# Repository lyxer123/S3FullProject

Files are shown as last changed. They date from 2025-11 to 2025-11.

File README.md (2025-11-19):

# 无线充电网关 (Wireless Charging Gateway)

## 项目概述

无线充电网关是一个基于ESP32-S3的智能网关设备，专为无线充电系统设计。该设备通过Modbus协议读取三相四线4P导轨电表的电压、电流、功率、电量等参数，并通过4G网络将数据传输到云平台。同时，网关还能接收云平台下发的控制指令，实现对无线充电原边控制柜的远程启停控制。

## 核心功能

### 1. 电表数据采集
- 通过Modbus RTU协议读取三相电表数据
- 采集参数包括：
  - 三相电压 (priThreePhaseVoltage)
  - 三相电流 (priThreePhaseCurrent)
  - 三相功率 (priThreePhasePower)
  - 三相电量 (priThreePhaseEnergy)
- 支持多种数据类型和字节序处理
- 可配置的采集间隔和系数转换

### 2. 远程控制
- 接收云平台下发的控制指令
- 控制无线充电原边设备的启停
- 支持多种控制命令格式

### 3. 云平台通信
- 基于MQTT协议与云平台通信
- 自动连接和重连机制
- 数据加密传输
- 支持多种主题订阅和发布

### 4. 系统特性
- 多任务并发处理 (FreeRTOS)
- 看门狗监控确保系统稳定运行
- LittleFS文件系统存储配置文件
- 支持4G模块PPP连接
- 自动时间同步功能

## 技术规格

### 硬件平台
- 主控芯片：ESP32-S3
- 通信接口：RS485 (Modbus)
- 网络连接：4G (PPP)
- 供电要求：12V/1A

### 软件架构
- 开发框架：Arduino ESP32
- 构建工具：PlatformIO
- 依赖库：
  - ArduinoJson (v7.0.0)
  - PubSubClient (MQTT)
  - ModbusMaster
  - ArduinoHttpClient

### Modbus配置
- 波特率：9600 bps
- 数据格式：8N1 (8位数据，无校验，1位停止位)
- 从设备ID：2 (电表)
- 采集参数：
  - 电压：地址0，系数0.1
  - 电流：地址3，系数0.1
  - 功率：地址7，系数1
  - 电量：地址29，32位，大端序，系数0.01

## 系统架构

```
+------------------+     +------------------+     +------------------+
|   云平台         |<--->|   无线充电网关   |<--->|   三相电表       |
|                  |     |                  |     |                  |
| - MQTT通信       |     | - ESP32-S3       |     | - Modbus RTU     |
| - 数据监控       |     | - 4G连接         |     | - 电压/电流/功率 |
| - 远程控制       |     | - 多任务处理     |     | - 电量计量       |
|                  |     | - 数据采集       |     |                  |
+------------------+     +------------------+     +------------------+
                              ^      |
                              |      v
                              |  +------------------+
                              |  | 原边控制柜       |
                              |  |                  |
                              |  | - 充电控制       |
                              |  | - 状态反馈       |
                              |  +------------------+
                              +----------+
                                         |
                              +----------v----------+
                              | 串口控制命令 (可选)  |
                              +---------------------+
```

## 已实现功能

### 数据采集与传输
- [x] Modbus RTU协议读取三相电表数据
- [x] 实时采集电压、电流、功率、电量参数
- [x] 数据格式转换和系数处理
- [x] 定时上传数据到云平台
- [x] 数据JSON格式化和传输

### 远程控制
- [x] 接收并解析云平台控制指令
- [x] 控制无线充电设备启停
- [x] 支持多种命令格式解析
- [x] 命令执行状态反馈

### 网络通信
- [x] 4G模块PPP连接
- [x] MQTT协议通信
- [x] 自动重连机制
- [x] 数据加密传输
- [x] 多主题订阅管理

### 系统管理
- [x] 配置文件管理 (LittleFS)
- [x] 看门狗监控
- [x] 多任务调度 (FreeRTOS)
- [x] 内存管理优化
- [x] 异常处理和日志输出

## 性能指标

### 采集精度
- 电压测量精度：±0.5%
- 电流测量精度：±0.5%
- 功率测量精度：±1%
- 电量计量精度：±1%

### 通信性能
- 数据上传间隔：可配置 (默认1秒)
- MQTT连接稳定性：99.9%
- 命令响应时间：< 1秒
- 网络重连时间：< 10秒

### 系统稳定性
- 平均无故障时间：> 720小时
- 内存占用：< 200KB
- 启动时间：< 5秒
- 工作温度：-20°C ~ +70°C

## 接线说明

### 电源连接
1. 12V/1A电源适配器连接到网关电源接口

### 通信连接
1. RS485总线连接：
   - 一端连接三相电表 (用于读取电压、电流、功率、电量数据)
   - 另一端连接无线充电原边控制柜 (用于下发启动/停止命令)

### 网络连接
1. 4G天线连接到网关4G模块接口
2. SIM卡插入SIM卡槽

## 配置说明

### 设备配置
```json
{
  "deviceNum": "D1UX3HYYRJ7V",
  "userId": "1",
  "productId": "153",
  "mqttUserName": "myChargingSpot",
  "mqttPwd": "PPWFKRV28D06M50N",
  "mqttSecret": "K8J7726I58KRYA7B"
}
```

### MQTT主题
- 订阅主题：/153/D1UX3HYYRJ7V/+/get
- 发布主题：/153/D1UX3HYYRJ7V/+/post

## 项目成果

### 已完成
1. 硬件平台搭建和调试
2. Modbus通信协议实现
3. 4G网络连接和MQTT通信
4. 云平台数据上传和指令接收
5. 系统稳定性和可靠性优化

### 技术突破
1. 实现了ESP32-S3多任务并发处理
2. 解决了Modbus多设备通信问题
3. 优化了网络连接稳定性
4. 实现了配置文件动态加载
5. 完善了异常处理和系统监控

## 未来规划

### 功能扩展
1. 加入网页管理界面，可查看设备状态、修改设备参数、下发控制命令
2. 支持OTA固件升级
3. 增加本地存储功能，支持断网数据缓存
4. 扩展支持更多类型的传感器和设备

### 性能优化
1. 进一步优化内存使用
2. 提高数据采集频率和精度
3. 增强网络安全性和数据加密
4. 优化功耗管理

## 项目照片

### 设备外观
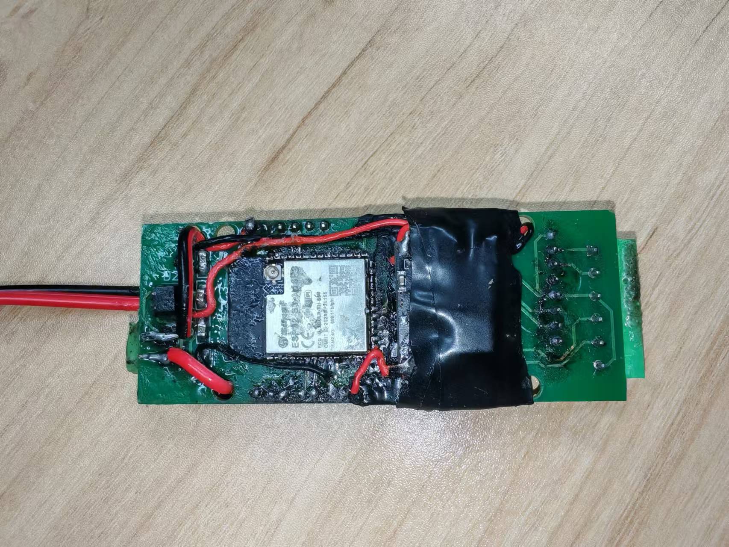
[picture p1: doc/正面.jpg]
正面

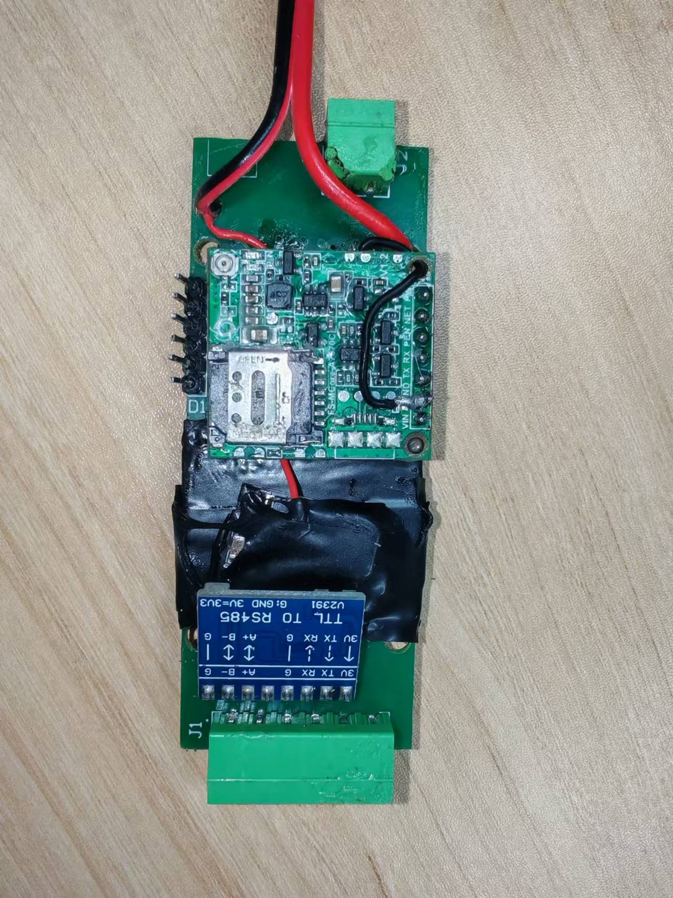
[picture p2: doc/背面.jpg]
背面


### 工作场景
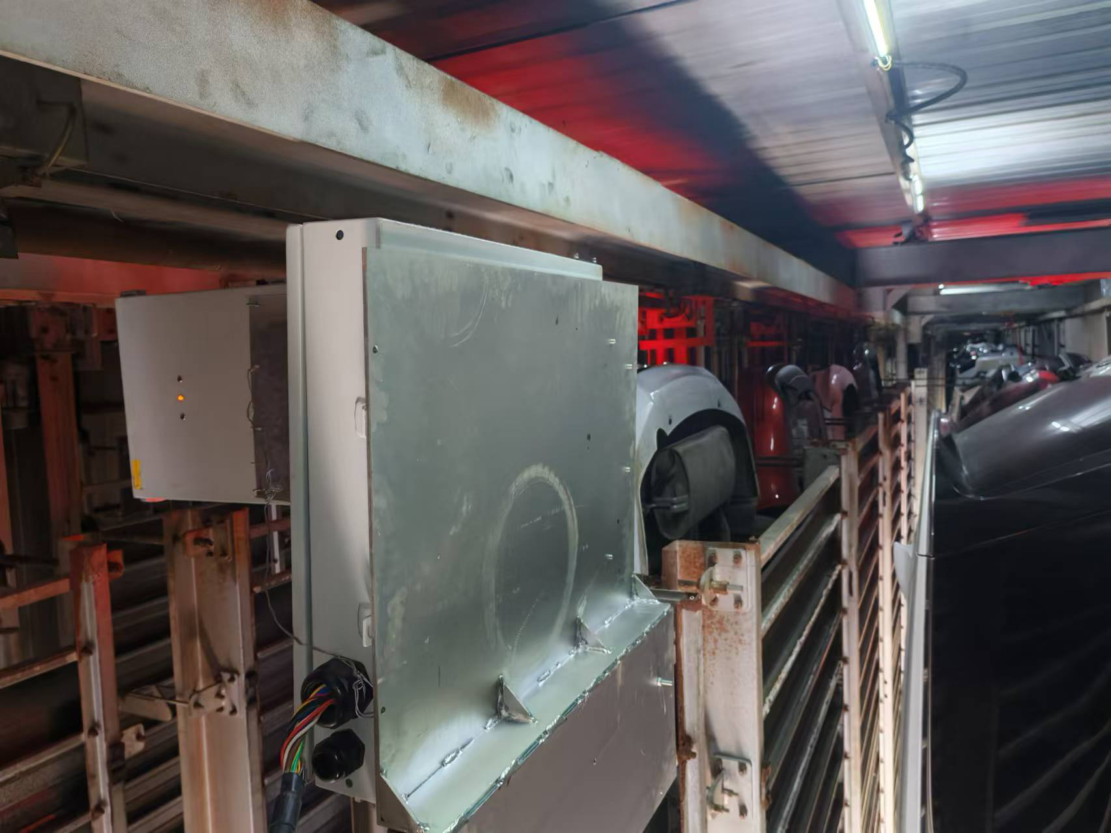
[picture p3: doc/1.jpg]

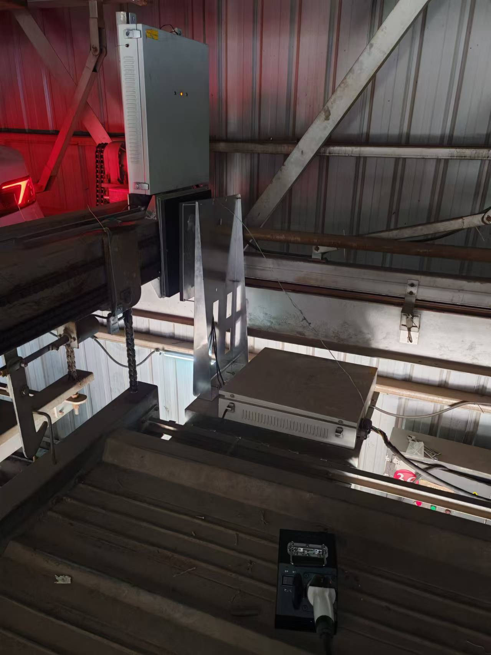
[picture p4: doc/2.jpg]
二楼车库视觉工作中

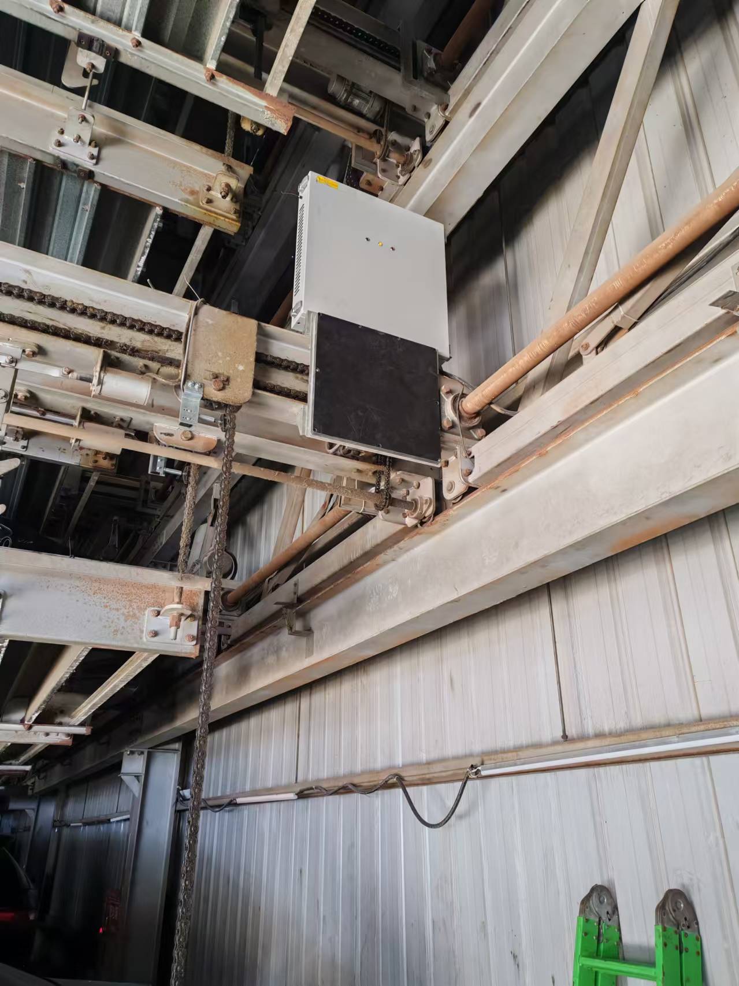
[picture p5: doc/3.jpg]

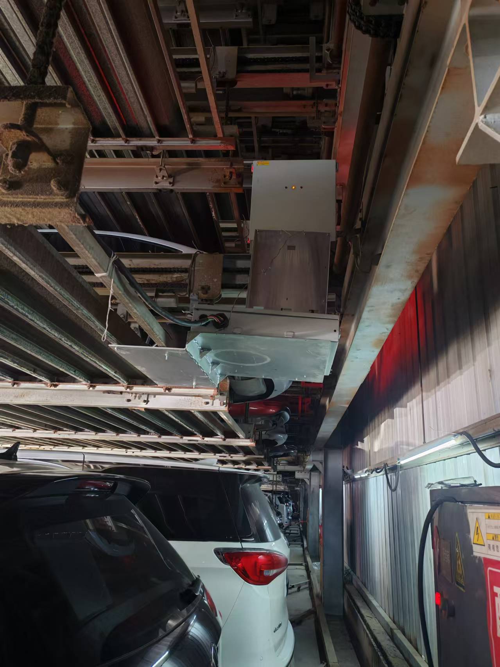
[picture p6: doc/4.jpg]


### 硬件连接
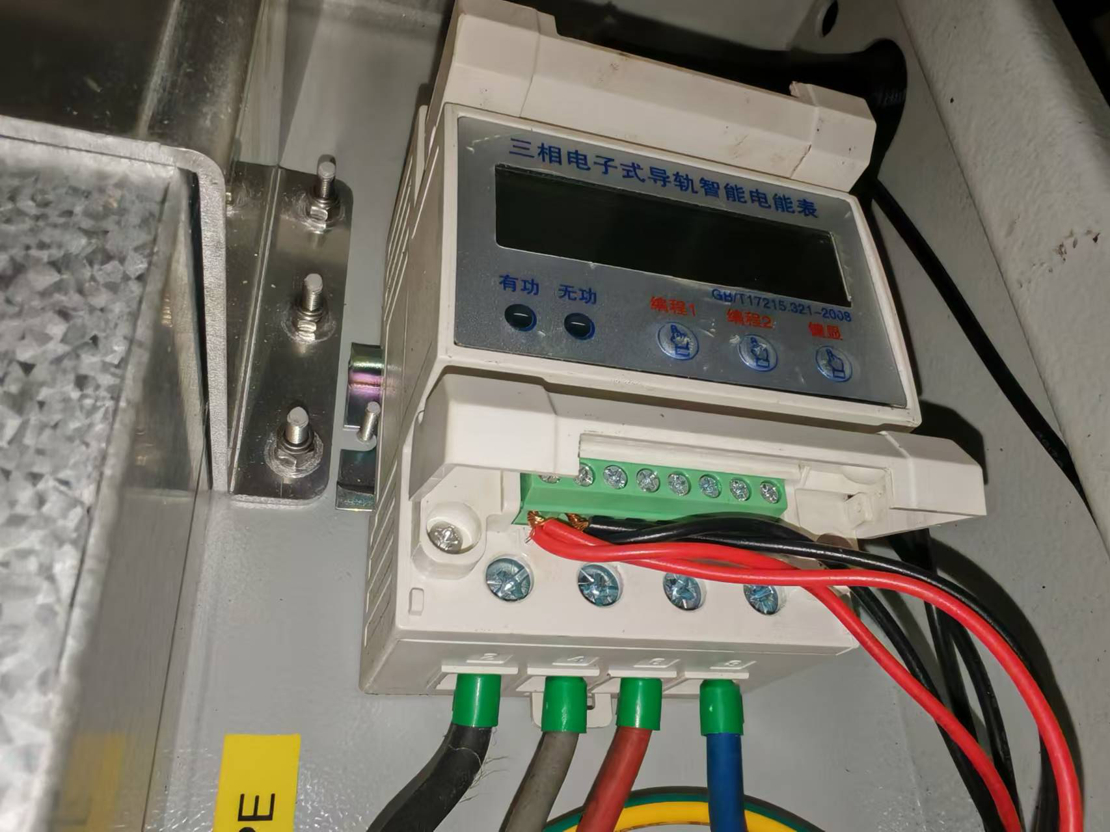
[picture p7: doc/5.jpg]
modbus电表


### 命令测试
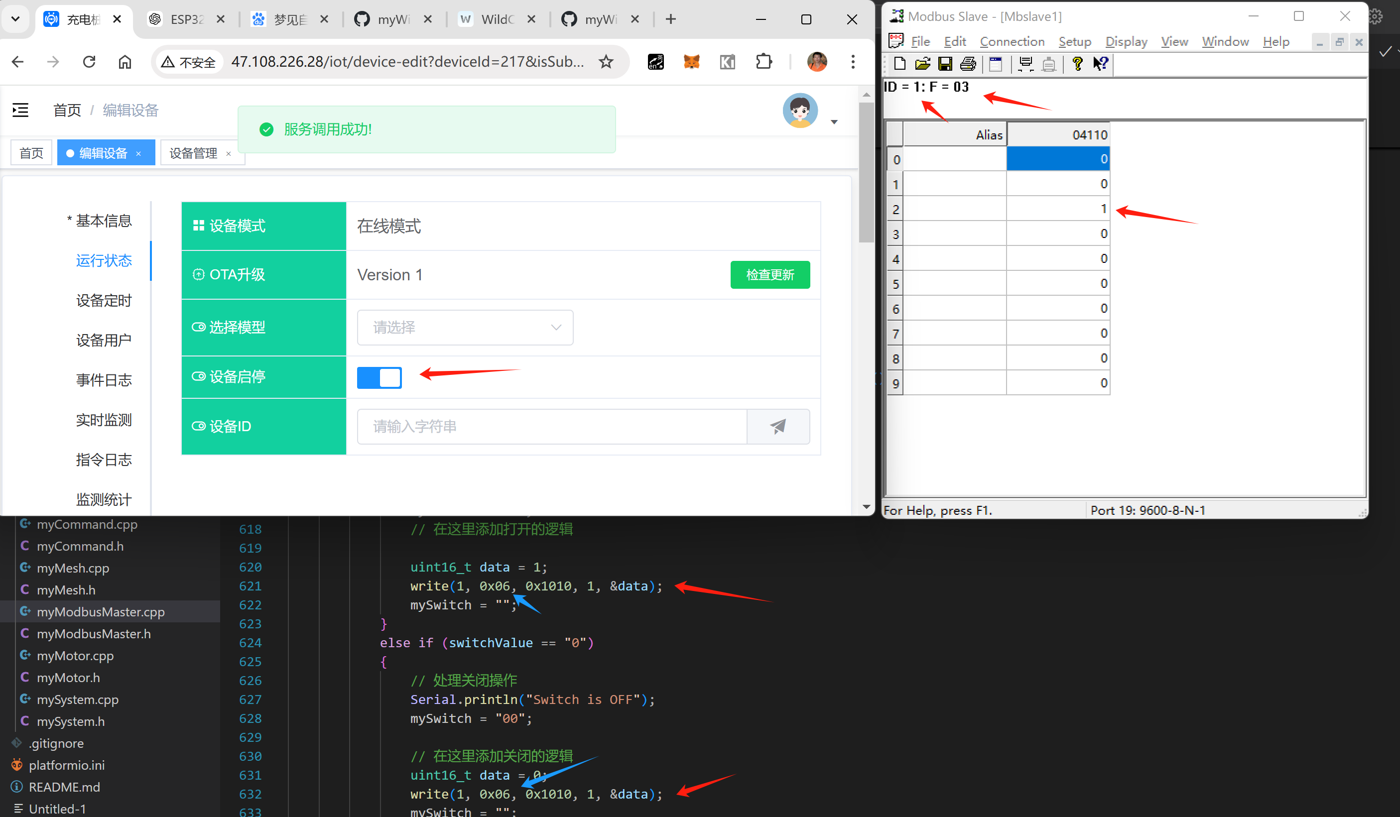
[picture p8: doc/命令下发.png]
命令下发


## 开发环境

### 硬件要求
- ESP32-S3开发板
- 三相四线4P导轨电表
- 4G模块和天线
- RS485转TTL模块

### 软件环境
- PlatformIO IDE
- Arduino ESP32框架 3.0.5
- 相关依赖库 (见platformio.ini)

## 编译和烧录

```bash
# 编译项目
pio run

# 烧录固件
pio run --target upload

# 烧录文件系统
pio run --target uploadfs
```

## 故障排除

### 常见问题
1. **Modbus通信失败**
   - 检查RS485接线是否正确
   - 确认电表地址和波特率设置
   - 验证Modbus配置文件

2. **4G连接失败**
   - 检查SIM卡是否正常
   - 确认天线连接良好
   - 查看信号强度指示

3. **MQTT连接问题**
   - 验证服务器地址和端口
   - 检查用户名密码配置
   - 确认网络连接状态

### 调试命令
通过串口发送以下命令进行调试：
- `A0`/`B0`/`C0`: 关闭对应通道
- `A1`/`B1`/`C1`: 打开对应通道
- `resetboard`: 重启设备

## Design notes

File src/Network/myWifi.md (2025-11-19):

# myWifi - ESP32 WiFi管理模块

一个功能完整的ESP32 WiFi管理模块,提供智能的AP/STA切换和Web配网功能。

## 核心特性

- **多模式支持**: AP、STA、AP+STA混合模式自动切换
- **NVS配置存储**: 自动保存和读取WiFi配置
- **智能重连机制**: 断线立即启动AP+STA模式,后台持续重连
- **Web配网门户**: 类似WiFiManager的现代化配网界面
- **零等待切换**: 断线后立即提供AP服务,无需等待
- **自动恢复**: 重连成功后自动切换回STA模式

## 快速开始

### 基本使用

```cpp
#include "Network/myWifi.h"

void setup() {
    Serial.begin(115200);
    myWiFi.begin();  // 初始化WiFi
}

void loop() {
    myWiFi.handle();  // 必须调用以处理WiFi状态
}
```

### 获取状态

```cpp
// 检查连接状态
if (myWiFi.isConnected()) {
    Serial.println("IP: " + myWiFi.getLocalIP());
    Serial.println("SSID: " + myWiFi.getConnectedSSID());
    Serial.println("信号: " + String(myWiFi.getRSSI()) + " dBm");
}

// 获取当前模式
wifi_mode_t mode = myWiFi.getCurrentMode();
// WIFI_MODE_STA = 1, WIFI_MODE_AP = 2, WIFI_MODE_APSTA = 3
```

## 工作原理

### 启动流程
```
1. 读取NVS配置
   ├─ 有配置? 尝试连接WiFi
   │  ├─ 成功 → STA模式运行
   │  └─ 失败 → AP配网模式
   └─ 无配置 → AP配网模式
```

### 智能重连机制 (v1.2+)

**断线后立即响应:**
```
检测到断线 (0秒)
  ↓
立即启动AP+STA混合模式
  ├─ [AP线程] 提供配网服务 (192.168.4.1)
  └─ [STA线程] 后台持续重连原热点
       ↓
     重连成功
       ↓
     自动关闭AP,切换回STA模式
```

**优势:**
- ⚡ **零等待**: 断线后立即可访问设备
- ✅ **高可用**: 配网和重连并行进行
- 🔄 **自动化**: 连接成功自动切换模式
- 🎯 **灵活**: 随时可重新配置WiFi

## Web配网界面

当设备进入AP配网模式时:

1. 连接热点: `ESP32-Gateway` (密码: `12345678`)
2. 打开浏览器访问: `192.168.4.1`
3. 点击"Scan Networks"扫描可用WiFi
4. 选择网络,输入密码
5. 点击"Save & Connect"

设备会自动尝试连接,成功后自动切换到STA模式。

## 配置参数

### 默认设置 (myWifi.h)

```cpp
// AP热点配置
#define DEFAULT_AP_SSID "ESP32-Gateway"
#define DEFAULT_AP_PASSWORD "12345678"

// 连接参数
#define WIFI_CONNECT_TIMEOUT 10000        // 连接超时: 10秒
#define WIFI_RECONNECT_INTERVAL 5000      // 快速重连: 5秒
#define WIFI_RECONNECT_INTERVAL_SLOW 30000 // 慢速重连: 30秒
#define WIFI_CHECK_INTERVAL 5000          // 状态检查: 5秒
#define AP_CHECK_STA_INTERVAL 3000        // AP模式检测: 3秒
```

### 智能重连策略

- 前3次: 5秒快速重连
- 3次后: 30秒慢速重连
- 断线后: 立即尝试重连(不等待)

## API参考

### 初始化

| 函数 | 说明 | 返回值 |
|---|---|---|
| `begin()` | 初始化WiFi模块 | bool |
| `handle()` | 处理WiFi状态(必须在loop中调用) | void |

### 状态查询

| 函数 | 说明 | 返回值 |
|---|---|---|
| `isConnected()` | 是否已连接 | bool |
| `getConnectedSSID()` | 获取已连接的SSID | String |
| `getLocalIP()` | 获取本地IP地址 | String |
| `getAPIP()` | 获取AP IP地址 | String |
| `getRSSI()` | 获取信号强度 | int (dBm) |
| `getCurrentMode()` | 获取当前模式 | wifi_mode_t |
| `getStatus()` | 获取当前状态 | WiFiStatus_t |

### 配置管理

| 函数 | 说明 | 返回值 |
|---|---|---|
| `setSTACredentials(ssid, pwd)` | 设置并保存STA凭据 | bool |
| `setAPCredentials(ssid, pwd)` | 设置并保存AP凭据 | bool |
| `clearConfig()` | 清除所有配置 | void |
| `startConfigPortal()` | 手动启动配网门户 | void |

## 高级用法

### 监听状态变化

```cpp
WiFiStatus_t lastStatus = WIFI_STATUS_IDLE;

void loop() {
    myWiFi.handle();
    
    WiFiStatus_t currentStatus = myWiFi.getStatus();
    if (currentStatus != lastStatus) {
        if (currentStatus == WIFI_STATUS_CONNECTED) {
            Serial.println("WiFi已连接!");
            // 启动需要网络的服务
        } else if (currentStatus == WIFI_STATUS_DISCONNECTED) {
            Serial.println("WiFi断开连接!");
            // 停止网络服务
        }
        lastStatus = currentStatus;
    }
}
```

### 信号强度监控

```cpp
if (myWiFi.isConnected()) {
    int rssi = myWiFi.getRSSI();
    if (rssi > -50) {
        Serial.println("信号优秀");
    } else if (rssi > -70) {
        Serial.println("信号良好");
    } else {
        Serial.println("信号较弱");
    }
}
```

## 测试指南

### 基础功能测试

1. ✅ 首次启动进入AP模式
2. ✅ Web配网功能正常
3. ✅ WiFi扫描成功
4. ✅ 配网后无崩溃
5. ✅ 配置保存到NVS
6. ✅ 重启后自动连接

### 断线重连测试

1. 设备正常连接WiFi
2. 关闭路由器
3. **立即**: ESP32进入AP+STA模式(无等待)
4. 可以连接AP进行配网
5. 重新打开路由器
6. ESP32自动重连成功
7. 自动关闭AP,切回STA模式

### 预期串口日志

**正常运行:**
```
[WiFi] Connected! IP: 192.168.1.100
[WiFi] RSSI: -45 dBm
```

**检测到断线:**
```
[WiFi] Connection lost!
[WiFi] Starting AP+STA mode for reconnection...
[WiFi] AP IP address: 192.168.4.1
```

**自动重连成功:**
```
[WiFi] Reconnected successfully! IP: 192.168.1.100
[WiFi] Switching to STA mode...
```

## 故障排除

### 问题1: 无法连接WiFi
- 检查SSID和密码是否正确
- 检查路由器是否正常工作
- 查看串口输出的错误信息

### 问题2: 配网页面无法打开
- 确认已连接到ESP32的AP热点
- 尝试访问 `192.168.4.1`
- 检查防火墙设置

### 问题3: 频繁断线重连
- 检查WiFi信号强度 (RSSI)
- 可能是路由器距离太远
- 建议信号强度 > -70 dBm

### 问题4: NVS保存失败
- 检查分区表配置
- 确保NVS分区足够大(至少20KB)
- 可以尝试 `myWiFi.clearConfig()` 清除配置

## 技术亮点

### 1. 延迟停止机制 (防止崩溃)

**问题**: 在Web回调中删除WebServer对象会导致Use-After-Free崩溃

**解决方案**: 
```cpp
// 在回调中设置标志
void handleSave() {
    shouldStopPortal = true;
    portalStopTime = millis() + 2000;
}

// 在主循环中安全删除
void handle() {
    if (shouldStopPortal && currentTime >= portalStopTime) {
        stopConfigPortal();  // 安全删除
    }
}
```

### 2. AP+STA并行工作

- AP模式提供配网服务
- STA模式后台持续重连
- 两者互不干扰,自动协调

### 3. 智能重连策略

- 前3次: 快速重连(5秒)
- 之后: 慢速重连(30秒)
- 断线立即尝试(无等待)
- 成功后重置计数器

## 性能指标

| 指标 | 数值 |
|---|---|
| 配网页面加载时间 | < 2秒 |
| WiFi扫描时间 | 2-5秒 |
| 连接WiFi时间 | 3-10秒 |
| 断线响应时间 | 立即 |
| AP服务可用时间 | 立即 |
| 内存占用(运行) | ~50KB |
| 内存占用(配网) | ~100KB |

## 注意事项

1. **必须调用handle()**: 在 `loop()` 中必须定期调用
2. **AP密码长度**: 至少8个字符
3. **内存占用**: AP+STA模式增加约50KB内存占用
4. **非阻塞设计**: 所有操作都是非阻塞的
5. **Flash要求**: 确保分区表中NVS分区至少20KB

## 版本历史

- **v1.0** (2025-01-19) - 初始版本
- **v1.1** (2025-01-19) - 修复StoreProhibited崩溃问题
- **v1.2** (2025-01-19) - AP/STA智能切换机制
  - 断线立即启动AP+STA
  - 持续重连不中断服务
  - 智能快速/慢速重连策略

## 分区表要求

使用 `esp32s3_4mb_partitions.csv`:

```csv
# Name,   Type, SubType, Offset,  Size
nvs,      data, nvs,     0x9000,  0x5000,  # 20KB (必需)
otadata,  data, ota,     0xE000,  0x2000,
app0,     app,  ota_0,   0x10000, 0x140000,
app1,     app,  ota_1,   0x150000,0x140000,
spiffs,   data, spiffs,  0x290000,0x160000,
```

## 技术支持

遇到问题请检查串口输出,所有重要操作都有详细日志。

---

**开发环境**: PlatformIO + ESP32-S3  
**测试设备**: ESP32-S3-DevKitC-1 (4MB Flash)  
**依赖库**: ESP32 WiFi, WebServer, DNSServer, Preferences

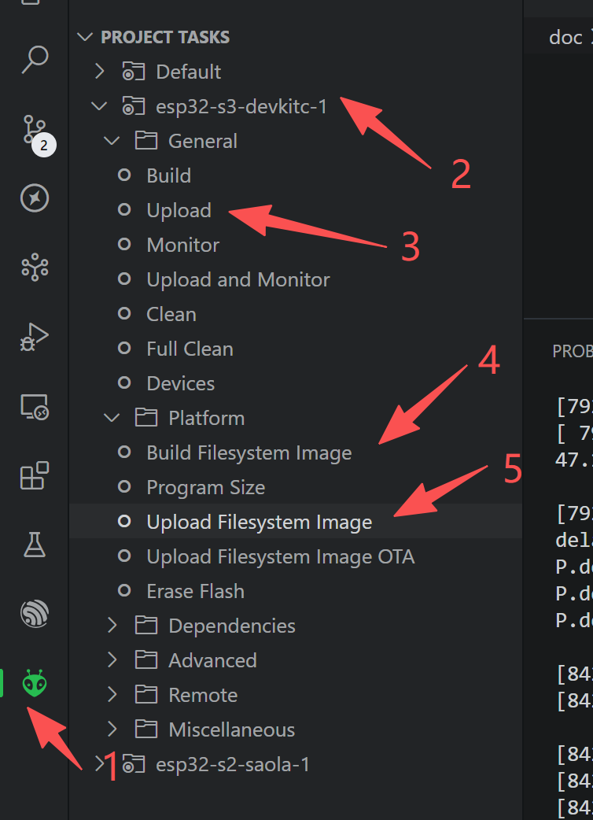
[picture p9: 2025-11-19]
doc/下载flash程序以及文件系统镜像.png

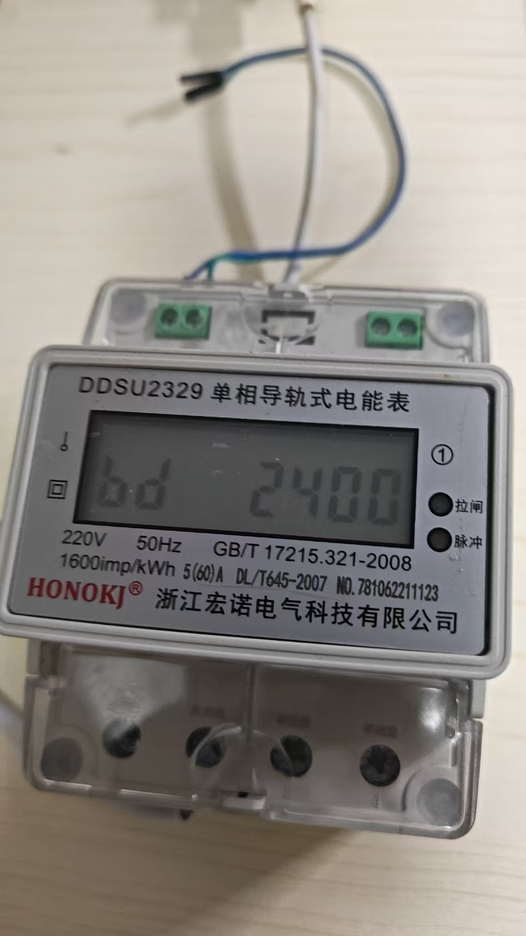
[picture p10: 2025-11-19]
doc/浙江宏诺电气_645表没找到资料.jpg

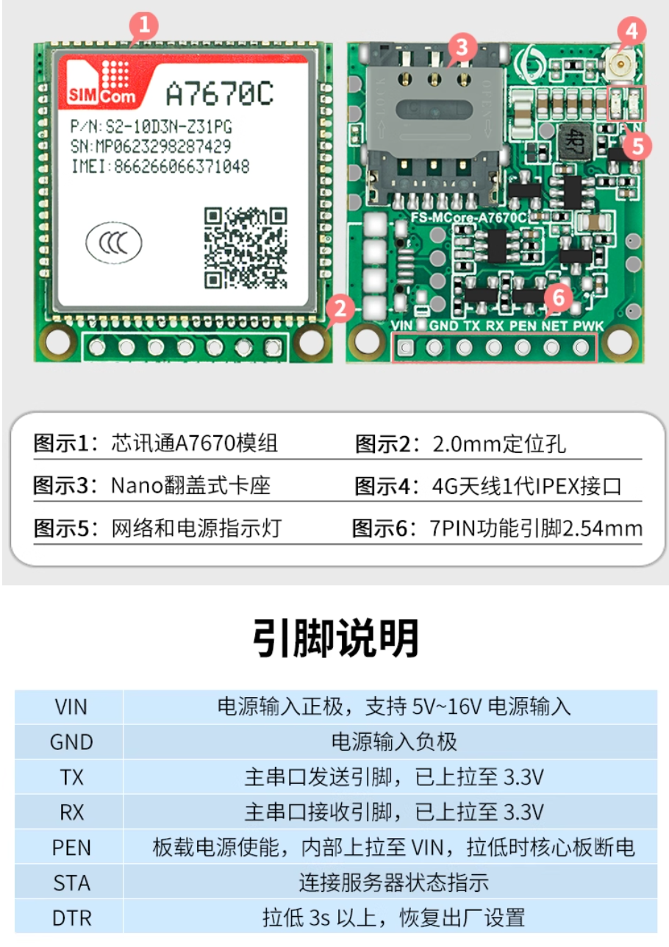
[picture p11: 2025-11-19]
doc/使用的4G模块定义.png

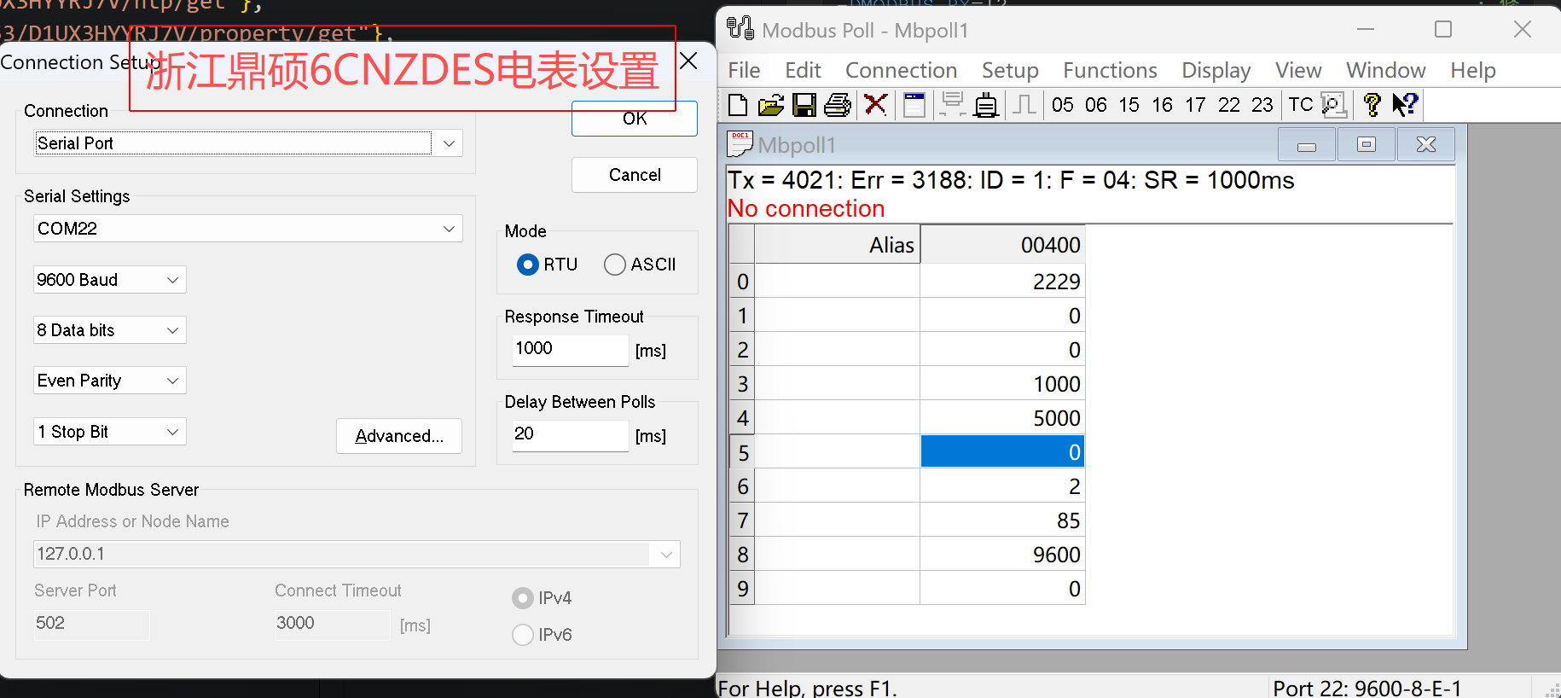
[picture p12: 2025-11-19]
doc/鼎硕电表设置.png

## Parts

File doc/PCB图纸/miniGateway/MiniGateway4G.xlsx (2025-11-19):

Line # | Name | Description | Designator | Quantity | Manufacturer 1 | Manufacturer Part Number 1 | Manufacturer Lifecycle 1 | Supplier 1 | Supplier Part Number 1 | Supplier Unit Price 1 | Supplier Subtotal 1
 | 10uF/0603 | Capacitor (Semiconductor SIM Model) | C1, C44 | 2
 | 10uF/0603 | CAP CER SMD 0805 22PF 5% 50V X7R | C2 | 1 | KEMET | C0805C220J5RAC7800 | Unknown | Digikey | 399-17625-1-ND | 0.13 | 0.13
 | 0.1uF/0603 | CAP CER SMD 0805 22PF 5% 50V X7R | C3 | 1 | KEMET | C0805C220J5RAC7800 | Unknown | Digikey | 399-17625-1-ND | 0.13 | 0.13
 | 0.1uF/0603 | CAP CER SMD 0805 22PF 5% 50V X7R | C4, C5 | 2 | KEMET | C0805C220J5RAC7800 | Unknown | Digikey | 399-17625-1-ND | 0.13 | 0.26
 | 0.1uF/0603 |  | C6, C29 | 2
 | 22pF/0603 |  | C7, C8 | 2
 | 1uF/0603 | CAP CER SMD 0805 22PF 5% 50V X7R | C9 | 1 | KEMET | C0805C220J5RAC7800 | Unknown | Digikey | 399-17625-1-ND | 0.13 | 0.13
 | 330pF/0603 | SURFACE MOUNT CAPACITOR 0.031 X 0.061 INCHES | C17 | 1
 | 0.1uF/0603 | SURFACE MOUNT CAPACITOR 0.031 X 0.061 INCHES | C18, C21 | 2
 | 22uF/1210 | SURFACE MOUNT CAPACITOR 0.031 X 0.061 INCHES | C19 | 1
 | 22uF/1210 | SURFACE MOUNT CAPACITOR 0.031 X 0.061 INCHES | C20 | 1
 | 10uF/1210 | SURFACE MOUNT CAPACITOR 0.031 X 0.061 INCHES | C22 | 1
 | 0.1uF/0603 |  | C41 | 1
 | 0.1uF/0603 | Capacitor (Semiconductor SIM Model) | C43 | 1
 | MX3.0MM-2X6P | https://detail.tmall.com/item.htm?id=771937830603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 | CN1 | 1
 | LESD5D5.0CT1G | Bi-Directional 5V SOD-523 Electrostatic and Surge Protection | D1, D4, D5 | 3
 | SM712 | 兩路TVS二极管阵列 | D2, D3 | 2
 | SIM-TF二合一卡座 | https://item.taobao.com/item.htm?id=837703746366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 | J | 1
 | Jumper | Header, 2-Pin | J1, J2 | 2
 | TYPEC Side Plug | https://item.taobao.com/item.htm?id=737479749412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 | J3 | 1
 | 10uH | 0503贴片电感 | L3 | 1
 | 0603LED-红 | 0603LED-红，兼容直插 | LED1, LED2, LED3 | 3
 | Header 9 | Header, 9-Pin | P1 | 1
 | 2N7002 | Nmos 2N7000, 2N7002, NDS7002A | Q1, Q2, Q3 | 3
 | 10K/0603 | RES, PULSE, 0805, 5%, 100 OHM, 0 | R1, R5, R6 | 3 | Stackpole Electronics | RPC0805JT100R-UP | Unknown | Digikey | RPC0805JT100R-UPCT-ND | 0.15 | 0.45
 | 10k/0603 | RES, PULSE, 0805, 5%, 100 OHM, 0 | R2 | 1 | Stackpole Electronics | RPC0805JT100R-UP | Unknown | Digikey | RPC0805JT100R-UPCT-ND | 0.15 | 0.15
 | 4.7K/0603 |  | R3, R4 | 2
 | 120R/0603 | Resistor | R7 | 1
 | 2K/0603 |  | R8, R9, R10 | 3
 | 2k/0603 |  | R11 | 1
 | 125k/0603 | Resistor | R14 | 1
 | 2k/0603 | Resistor | R15, R17, R18 | 3
 | 30.0k/0603 | Resistor | R16 | 1
 | 30.0k/0603 |  | R28 | 1
 | 4.7k/0603 |  | R36, R39 | 2
 | 10K/0603 |  | R41 | 1
 | 120R/0603 |  | R42 | 1
 | 10k | 电阻排-4D03 | R43 | 1
 | SMA 4脚拐弯射频天线插座 | SMA 4脚拐弯射频天线插座 | RF1 | 1
 | SMA弯头外螺内孔转IPEX1代 | SMA 4脚拐弯射频天线插座，https://item.taobao.com/item.htm?abbucket=8&id=645371264157&ns=1&sku_properties=1627207:22096496743 | RF2 | 1
 | ME6217C33-SOT23-5 | 4.2v-3.3v LDO | U1 | 1
 | SCT2332TVBR | 3.8V-32V Vin, 3A Synchronous Step-down DCDC Converter | U2 | 1
 | ATECC608 | microchip 加密芯片 IIC，SOIC封装 | U3 | 1
 | A7680C | 4G cat1 module，https://item.taobao.com/item.htm?id=660889426967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 | U4 | 1
 | ESP32-S3-WROOM-1U N16R8 | wifi+BLE.腿脚兼容ESP32-S3 | U5 | 1
 | SP3485 | 485总线芯片 | U6 | 1
 | SN65HVD230DR | 3.3 V CAN Transceiver with Standby Mode | U7 | 1
 | TXS0102DCTTG4 | 2-Bit Bidirectional Voltage-Level Shifter for Open-Drain and Push-Pull Application 8-SM8 -40 to 85 | U8 | 1
 | SMF05CT1 | 12.5V Clamp 8A (8/20Âµs) Ipp Tvs Diode Surface Mount SC-88/SC70-6/SOT-363 | U9 | 1
 | CH340K | usb转串口，用于下载使用。 | U10 | 1

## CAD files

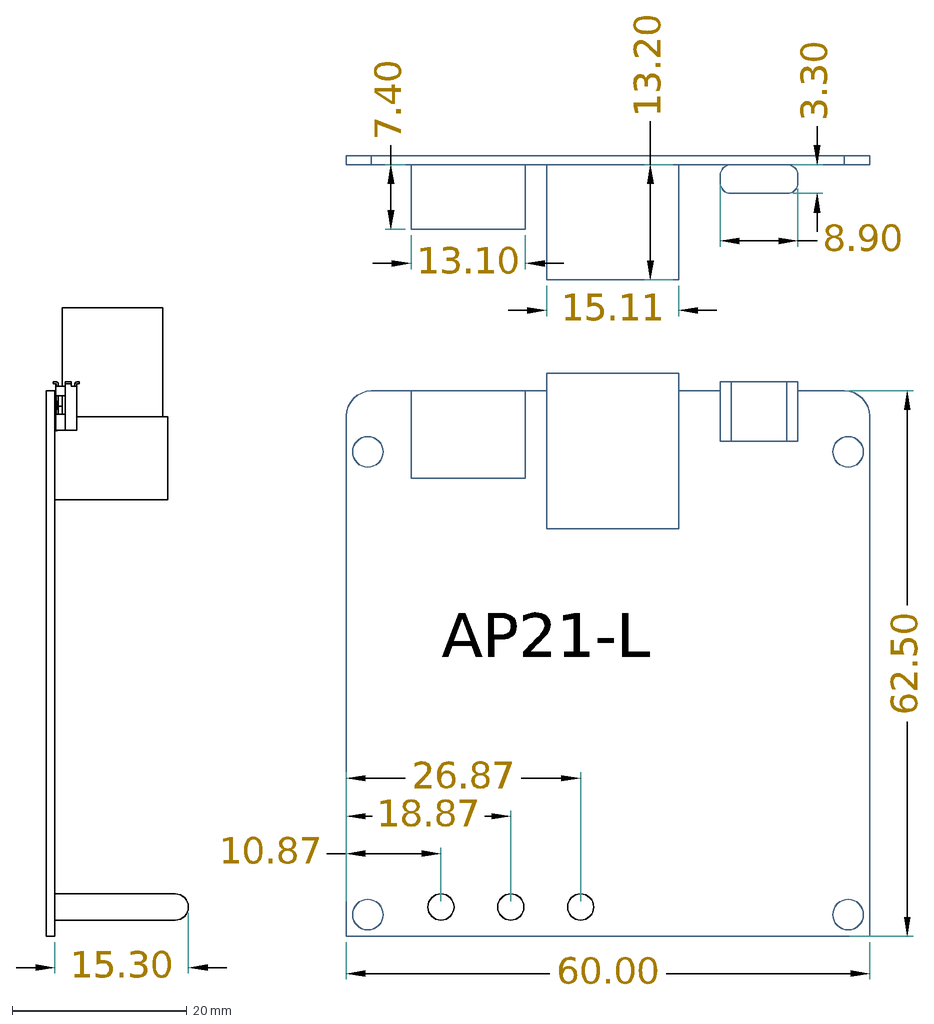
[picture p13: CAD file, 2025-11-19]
doc/PCB图纸/第三版/外壳/AP21L-PCB.dxf
13.20
7.40
13.10
15.11
3.30
8.90
60.00
10.87
18.87
AP21-L
26.87
62.50
15.30

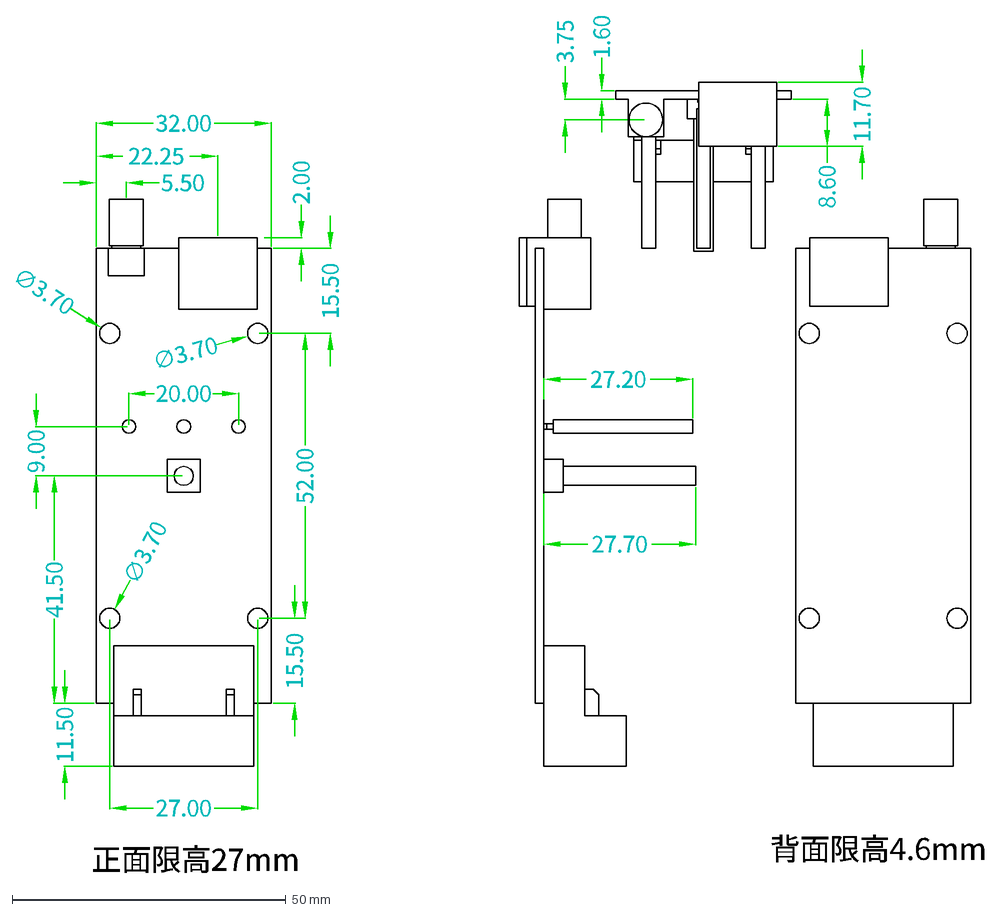
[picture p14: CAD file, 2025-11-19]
doc/PCB图纸/第二版简版/外壳/A16-pcb板框图.dxf
32.00
52.00
15.50
41.50
9.00
27.00
11.50
20.00
22.25
5.50
2.00
∅3.70
27.70
27.20
3.75
1.60
8.60
11.70
正面限高27mm
背面限高4.6mm

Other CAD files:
doc/PCB图纸/A17-pcb 板框图2.dwg
doc/PCB图纸/第一版/A17-pcb 板框图2.dwg
doc/PCB图纸/第三版/外壳/A17-pcb 板框图1.dwg
doc/PCB图纸/第二版简版/外壳/A17-pcb 板框图2.dwg
doc/PCB图纸/第一版/A17-pcb 板框图.dwg
doc/PCB图纸/第一版/A17-pcb 板框图1.dwg
doc/PCB图纸/第三版/外壳/A17-pcb 板框图2.dwg
doc/PCB图纸/第二版简版/外壳/A17-pcb 板框图.dwg
doc/PCB图纸/第三版/外壳/A17-pcb 板框图.dwg
doc/PCB图纸/第二版简版/外壳/NC-01.dxf
doc/PCB图纸/第三版/外壳/NC-01.dxf
doc/PCB图纸/第二版简版/外壳/A17-pcb 板框图1.dwg
doc/PCB图纸/第三版/外壳/A16-pcb板框图.dwg
doc/PCB图纸/第二版简版/外壳/A16-pcb板框图.dwg

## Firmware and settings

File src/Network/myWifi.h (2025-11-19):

// myWifi.h
#ifndef MY_WIFI_H
#define MY_WIFI_H

#include <Arduino.h>
#include <WiFi.h>
#include <WiFiClient.h>
#include <WebServer.h>
#include <Preferences.h>
#include <DNSServer.h>

// 默认配置值
#define DEFAULT_AP_SSID "ESP32-Gateway"        // 默认AP热点名称
#define DEFAULT_AP_PASSWORD "12345678"         // 默认AP密码(至少8位)
#define DEFAULT_STA_SSID ""                    // 默认STA连接的SSID(空表示无默认值)
#define DEFAULT_STA_PASSWORD ""                // 默认STA密码

// NVS存储的键名
#define NVS_NAMESPACE "wifi_config"
#define NVS_KEY_STA_SSID "sta_ssid"
#define NVS_KEY_STA_PASSWORD "sta_pwd"
#define NVS_KEY_AP_SSID "ap_ssid"
#define NVS_KEY_AP_PASSWORD "ap_pwd"

// WiFi连接参数
#define WIFI_CONNECT_TIMEOUT 10000             // WiFi连接超时时间(ms)
#define WIFI_RECONNECT_INTERVAL 5000           // 快速重连间隔(5秒)
#define WIFI_RECONNECT_INTERVAL_SLOW 30000     // 慢速重连间隔(30秒,失败3次后)
#define WIFI_MAX_RETRY_TIMES 999               // 最大重试次数(设置很大,持续重连)
#define WIFI_CHECK_INTERVAL 5000               // WiFi状态检查间隔(ms)
#define AP_CHECK_STA_INTERVAL 3000             // AP模式下检查STA连接的间隔(3秒,快速检测)

// DNS服务器配置
#define DNS_PORT 53
#define CAPTIVE_PORTAL_HOST "wifi.setup"

// WiFi状态枚举
enum WiFiStatus_t {
    WIFI_STATUS_IDLE = 0,           // 空闲状态
    WIFI_STATUS_CONNECTING,         // 正在连接
    WIFI_STATUS_CONNECTED,          // 已连接
    WIFI_STATUS_DISCONNECTED,       // 已断开
    WIFI_STATUS_AP_STARTED,         // AP已启动
    WIFI_STATUS_AP_STA_STARTED,     // AP+STA已启动
    WIFI_STATUS_RECONNECTING,       // 正在重连
    WIFI_STATUS_CONFIG_PORTAL       // 配网模式
};

class MyWiFi {
public:
    MyWiFi();
    ~MyWiFi();

    // 初始化WiFi
    bool begin();
    
    // 循环处理函数,需要在loop中调用
    void handle();
    
    // 获取当前WiFi状态
    WiFiStatus_t getStatus();
    
    // 获取当前WiFi模式
    wifi_mode_t getCurrentMode();
    
    // 获取连接的SSID
    String getConnectedSSID();
    
    // 获取本地IP地址(STA模式)
    String getLocalIP();
    
    // 获取AP IP地址
    String getAPIP();
    
    // 是否已连接到路由器
    bool isConnected();
    
    // 手动设置STA凭据并保存到NVS
    bool setSTACredentials(const String& ssid, const String& password);
    
    // 手动设置AP凭据并保存到NVS
    bool setAPCredentials(const String& ssid, const String& password);
    
    // 清除NVS中保存的WiFi配置
    void clearConfig();
    
    // 强制进入配网模式
    void startConfigPortal();
    
    // 断开连接并停止WiFi
    void disconnect();
    
    // 获取WiFi信号强度(RSSI)
    int getRSSI();
    
    // 获取连接的客户端数量(AP模式)
    int getConnectedClients();

private:
    // NVS偏好设置对象
    Preferences preferences;
    
    // Web服务器(用于配网)
    WebServer* webServer;
    
    // DNS服务器(用于强制门户)
    DNSServer* dnsServer;
    
    // WiFi配置信息
    String staSSID;
    String staPassword;
    String apSSID;
    String apPassword;
    
    // 状态变量
    WiFiStatus_t currentStatus;
    wifi_mode_t currentMode;
    unsigned long lastCheckTime;
    unsigned long lastReconnectTime;
    int reconnectAttempts;
    bool configPortalActive;
    unsigned long apModeStartTime;
    bool shouldStopPortal;
    unsigned long portalStopTime;
    
    // 内部功能函数
    bool loadConfig();                          // 从NVS加载配置
    bool saveConfig();                          // 保存配置到NVS
    void startSTA();                            // 启动STA模式
    void startAP();                             // 启动AP模式
    void startAPSTA();                          // 启动AP+STA模式
    bool connectToWiFi();                       // 连接到WiFi
    void handleReconnect();                     // 处理重连逻辑
    void handleConfigPortal();                  // 处理配网门户
    void setupWebServer();                      // 设置Web服务器
    void handleRoot();                          // 处理根页面请求
    void handleSave();                          // 处理保存配置请求
    void handleScan();                          // 处理WiFi扫描请求
    void handleStatus();                        // 处理状态查询请求
    void stopConfigPortal();                    // 停止配网门户
    String getConfigPortalHTML();               // 获取配网页面HTML
    String getStatusJSON();                     // 获取状态JSON
    void checkSTAConnection();                  // 检查STA连接状态
    void checkAPMode();                         // 在AP模式下检查是否可以连接STA
};

// 全局WiFi管理对象(外部声明,需在cpp中定义)
extern MyWiFi myWiFi;

#endif // MY_WIFI_H

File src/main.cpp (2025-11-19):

#include "main.h"
#include "Network/myWifi.h"

void setup()
{
  Serial.begin(115200);
  delay(1000);  // 给一些时间让串口初始化

  Serial.println("=================================");
  Serial.println("ESP32 Gateway Starting...");
  Serial.println("=================================");

  // 初始化WiFi
  Serial.println("\n[SETUP] Initializing WiFi...");
  myWiFi.begin();

  Serial.println("\n[SETUP] Setup completed.");
}

void loop()
{
  // 处理WiFi状态和自动重连
  myWiFi.handle();

  // 每10秒打印一次WiFi状态信息
  static unsigned long lastPrint = 0;
  if (millis() - lastPrint > 10000) {
    lastPrint = millis();
    
    Serial.println("\n========== WiFi Status ==========");
    Serial.printf("Mode: %d\n", myWiFi.getCurrentMode());
    Serial.printf("Status: %d\n", myWiFi.getStatus());
    
    if (myWiFi.isConnected()) {
      Serial.printf("Connected to: %s\n", myWiFi.getConnectedSSID().c_str());
      Serial.printf("IP Address: %s\n", myWiFi.getLocalIP().c_str());
      Serial.printf("Signal: %d dBm\n", myWiFi.getRSSI());
    } else {
      Serial.println("Not connected to WiFi");
      wifi_mode_t mode = myWiFi.getCurrentMode();
      if (mode == WIFI_MODE_AP || mode == WIFI_MODE_APSTA) {
        Serial.printf("AP IP: %s\n", myWiFi.getAPIP().c_str());
        Serial.printf("AP Clients: %d\n", myWiFi.getConnectedClients());
      }
    }
    Serial.println("=================================\n");
  }

  // 添加一个短暂的延迟,让其他任务有机会运行
  delay(10);
}
